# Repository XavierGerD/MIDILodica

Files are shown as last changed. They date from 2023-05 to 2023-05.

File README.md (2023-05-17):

# MIDILodica

## What is the MIDILodica?

<p align="center">
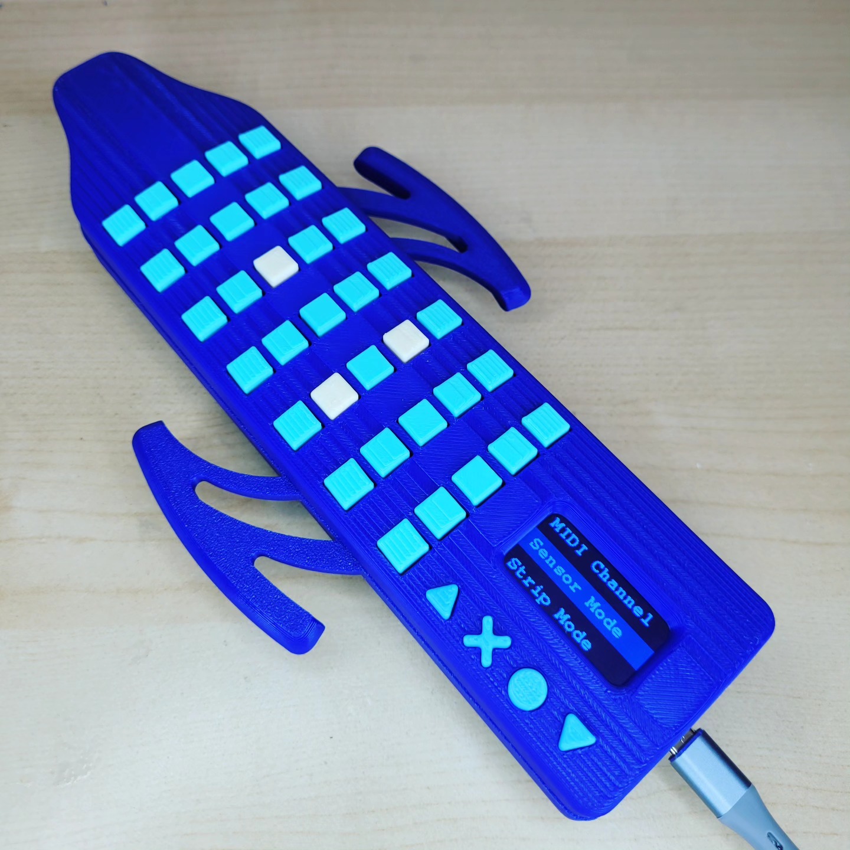
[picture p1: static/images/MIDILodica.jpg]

</p>

The MIDILodica is a breath-controlled, 3D printed, open-source MIDI device that features a pressure sensor, 35 reassignable note buttons, a softpot strip potentiometer, full menu navigation with a 320x172 screen, and underside button for additional MIDI and octave manipulation. This repository contains all the files needed to 3D print and manufacture the MIDILodica.

To accomplish this project, you will need:

- Basic knowledge of the Arduino IDE.
- Basic knowledge of and equipment for soldering.
- Access to a 3D printer.
- All the electronic parts listed below.

</br>

## Parts list

To build the MIDILodica, you will need the following:

- **40 x TL1105SPF160Q Tactile Switch** (can be substituted with TL1240NQ1JBLK if you don't have access to a 3D printer)
- **1x Adafruit 320x172 TFT Display - ST7789 (part no. 5393)** (with headers)
- **1x Arduino Micro** (with headers)
- **40x 1N4148 Through-hole diodes**
- **1x 10k through-hole resistor**
- **1x ABPDANT005PGAA5 Honeywell pressure sensor**
- **1x SEN-08680 50mm Softpot**
- **1x 66226-003LF 3pos clincher** (to replace the Softpot headers)
- **3x Male to Female jumper cables OR 1x 3pos Male to Female jumper cable**
- **1x 3pos right angle header** (to hold the sensor breakout board)
- **6x M2x20 screws** (for the housing)
- **4x M2x8 screws** (for the strip pot plate)

You will also need to obtain TWO printed circuit boards (PCB) with a PCB manufacturing service. The first one is the main board, which has all the buttons and breakout boards. The second PCB holds the sensor, and is attached at a 90 degree angle using the 3pos right angle header. The required files are in a .zip in the `/manufacturing/gerber` folder. If you wish to modify these boards, the `.sch` and `.brd` files are available in the `/manufacturing` folder.

</br>

## License

The project is under the GNU General Public License v3.0.

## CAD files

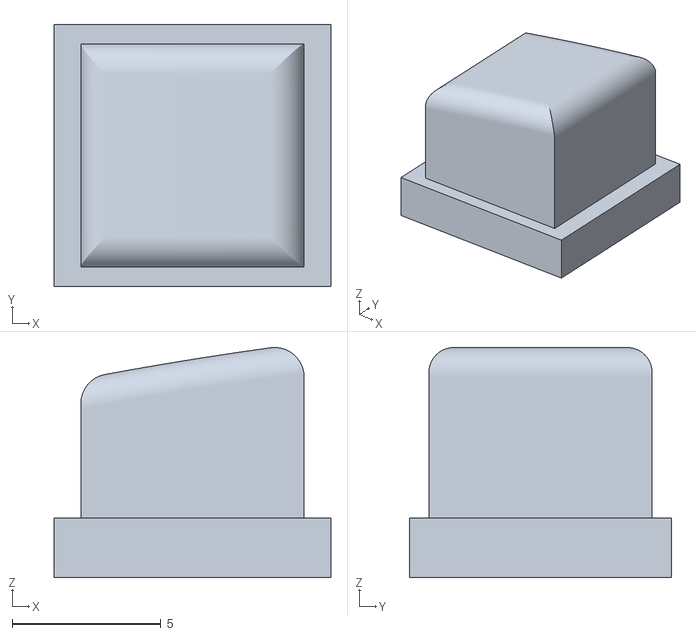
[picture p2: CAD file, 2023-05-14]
stl/Outer Button.stl
9.30 x 8.80 x 7.72

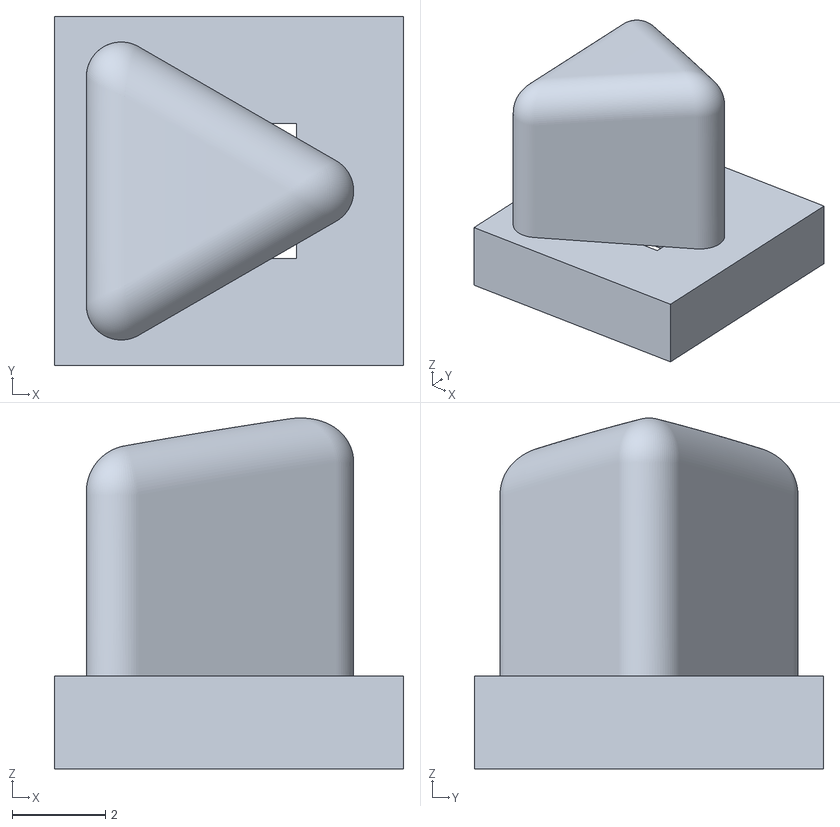
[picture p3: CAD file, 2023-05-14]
stl/Up Button.stl
7.50 x 7.50 x 7.54

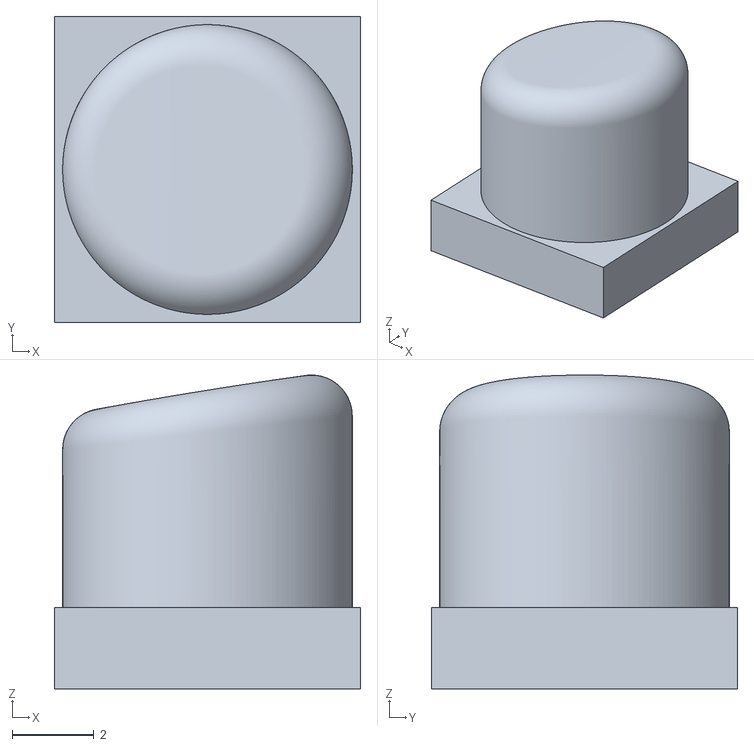
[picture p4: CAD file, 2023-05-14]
stl/Confirm Button.stl
7.50 x 7.50 x 7.69

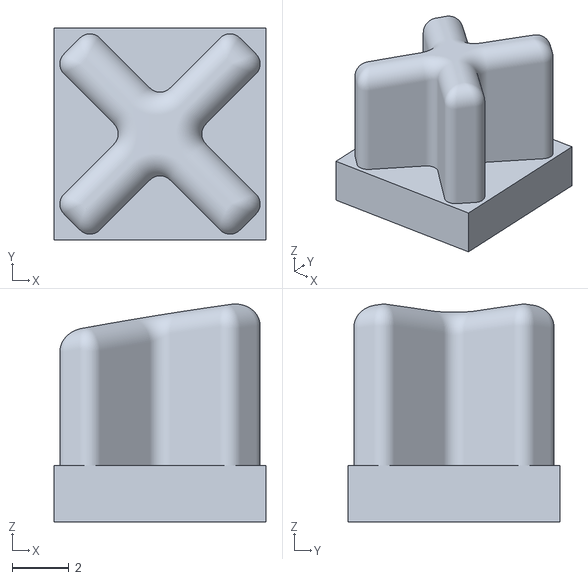
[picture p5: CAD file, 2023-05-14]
stl/Cancel Button.stl
7.50 x 7.50 x 7.71

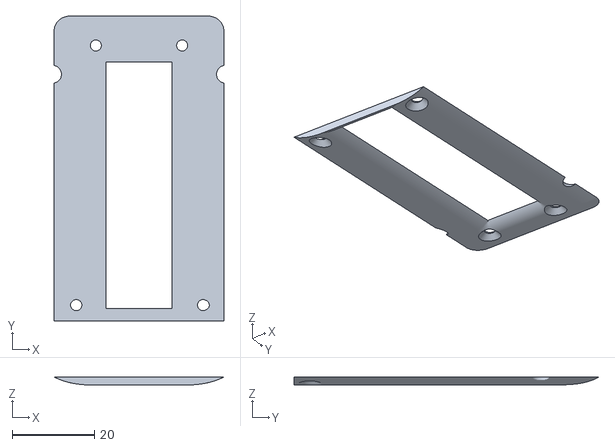
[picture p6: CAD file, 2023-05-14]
stl/Strip Cover.stl
41.3 x 74.2 x 2.00

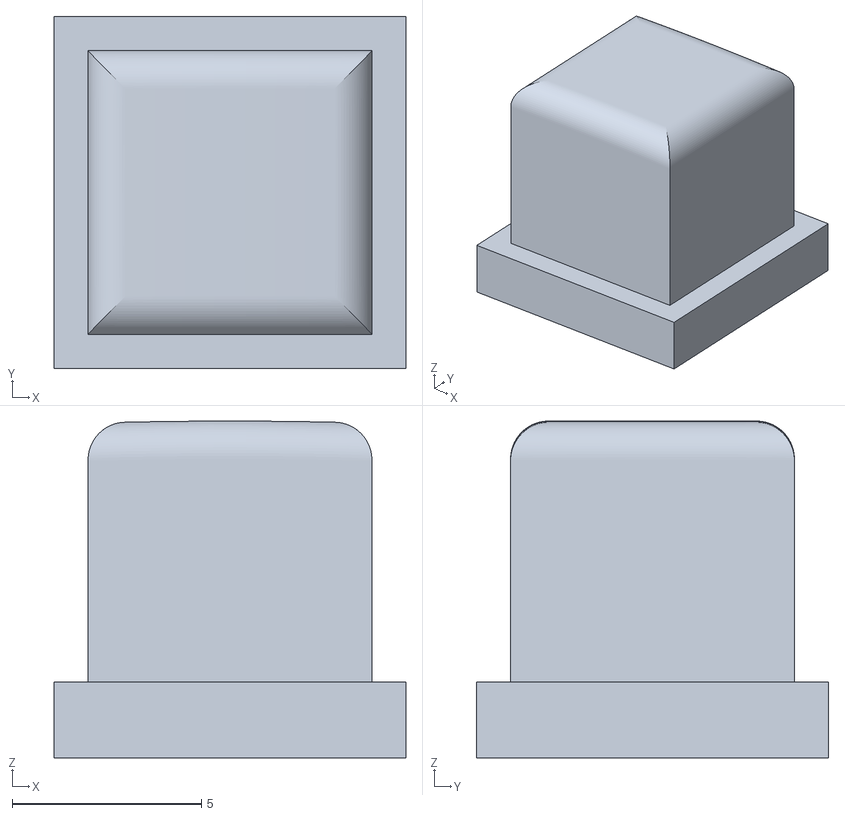
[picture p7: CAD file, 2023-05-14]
stl/Middle Button.stl
9.30 x 9.30 x 8.90

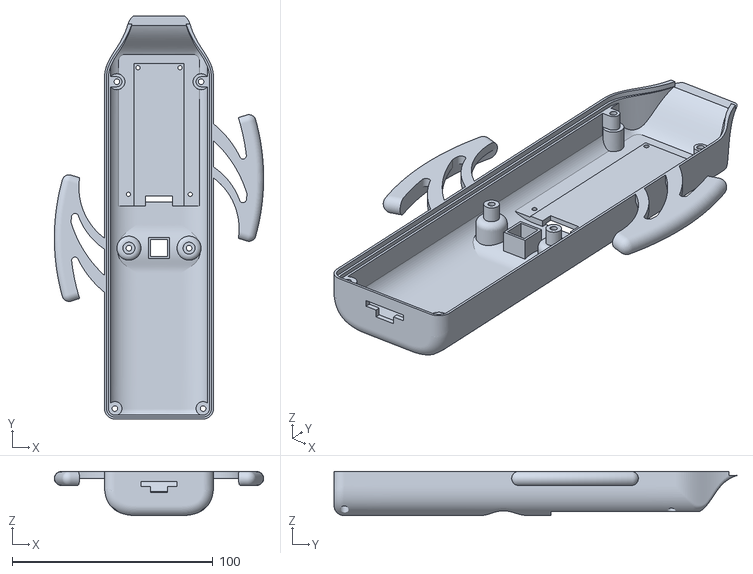
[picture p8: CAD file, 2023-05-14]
stl/Bottom_with_wings.stl
104.4 x 201.0 x 22.0

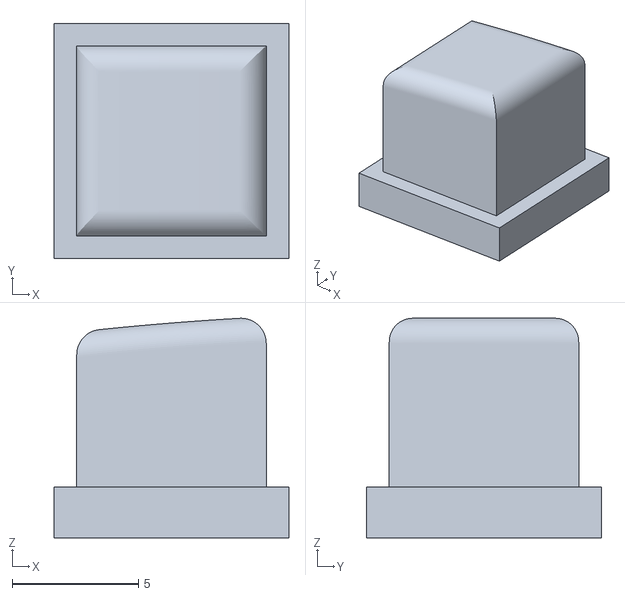
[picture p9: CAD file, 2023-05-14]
stl/Inner Button.stl
9.30 x 9.30 x 8.69

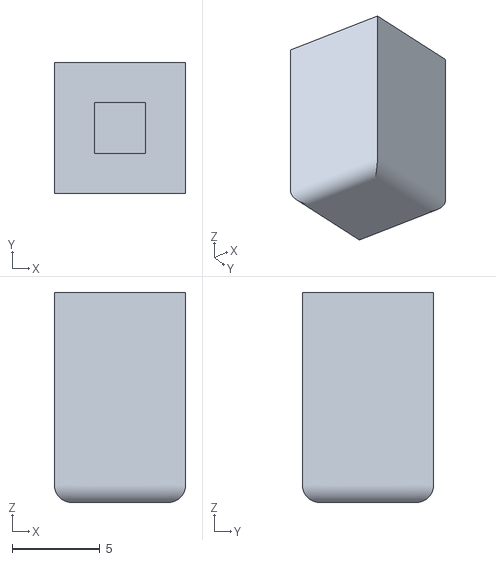
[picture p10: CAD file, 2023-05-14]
stl/Underbutton.stl
7.50 x 7.50 x 12.0

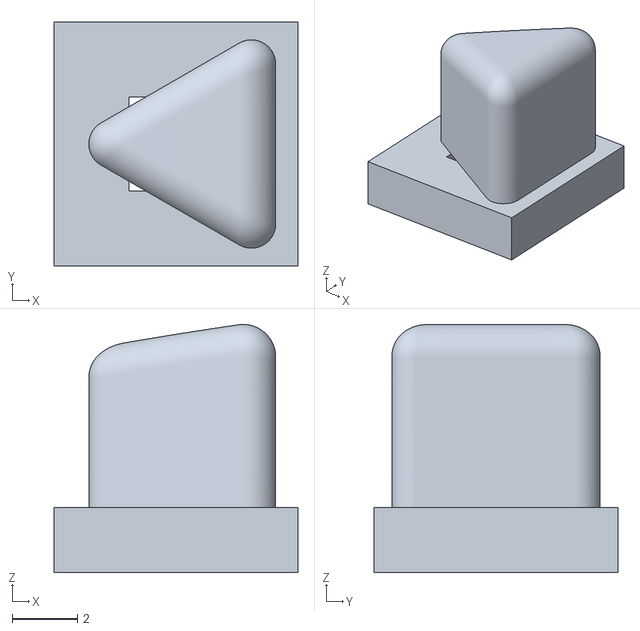
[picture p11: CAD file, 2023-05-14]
stl/Down Button.stl
7.50 x 7.50 x 7.63

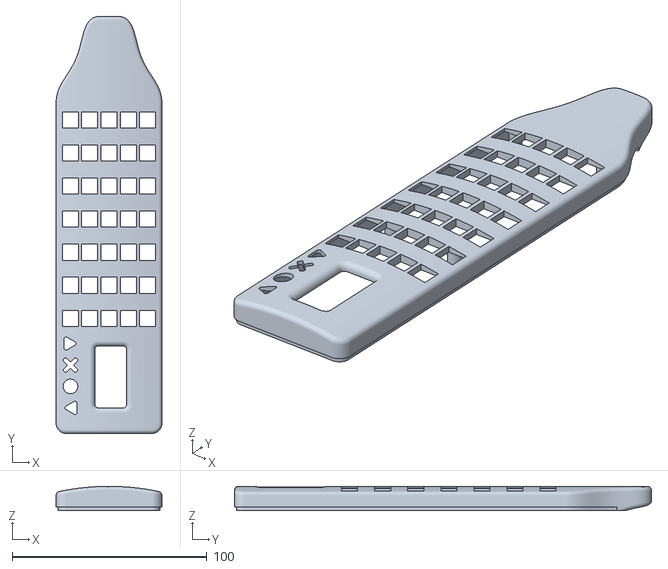
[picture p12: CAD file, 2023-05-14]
stl/Top.stl
54.4 x 214.4 x 12.5

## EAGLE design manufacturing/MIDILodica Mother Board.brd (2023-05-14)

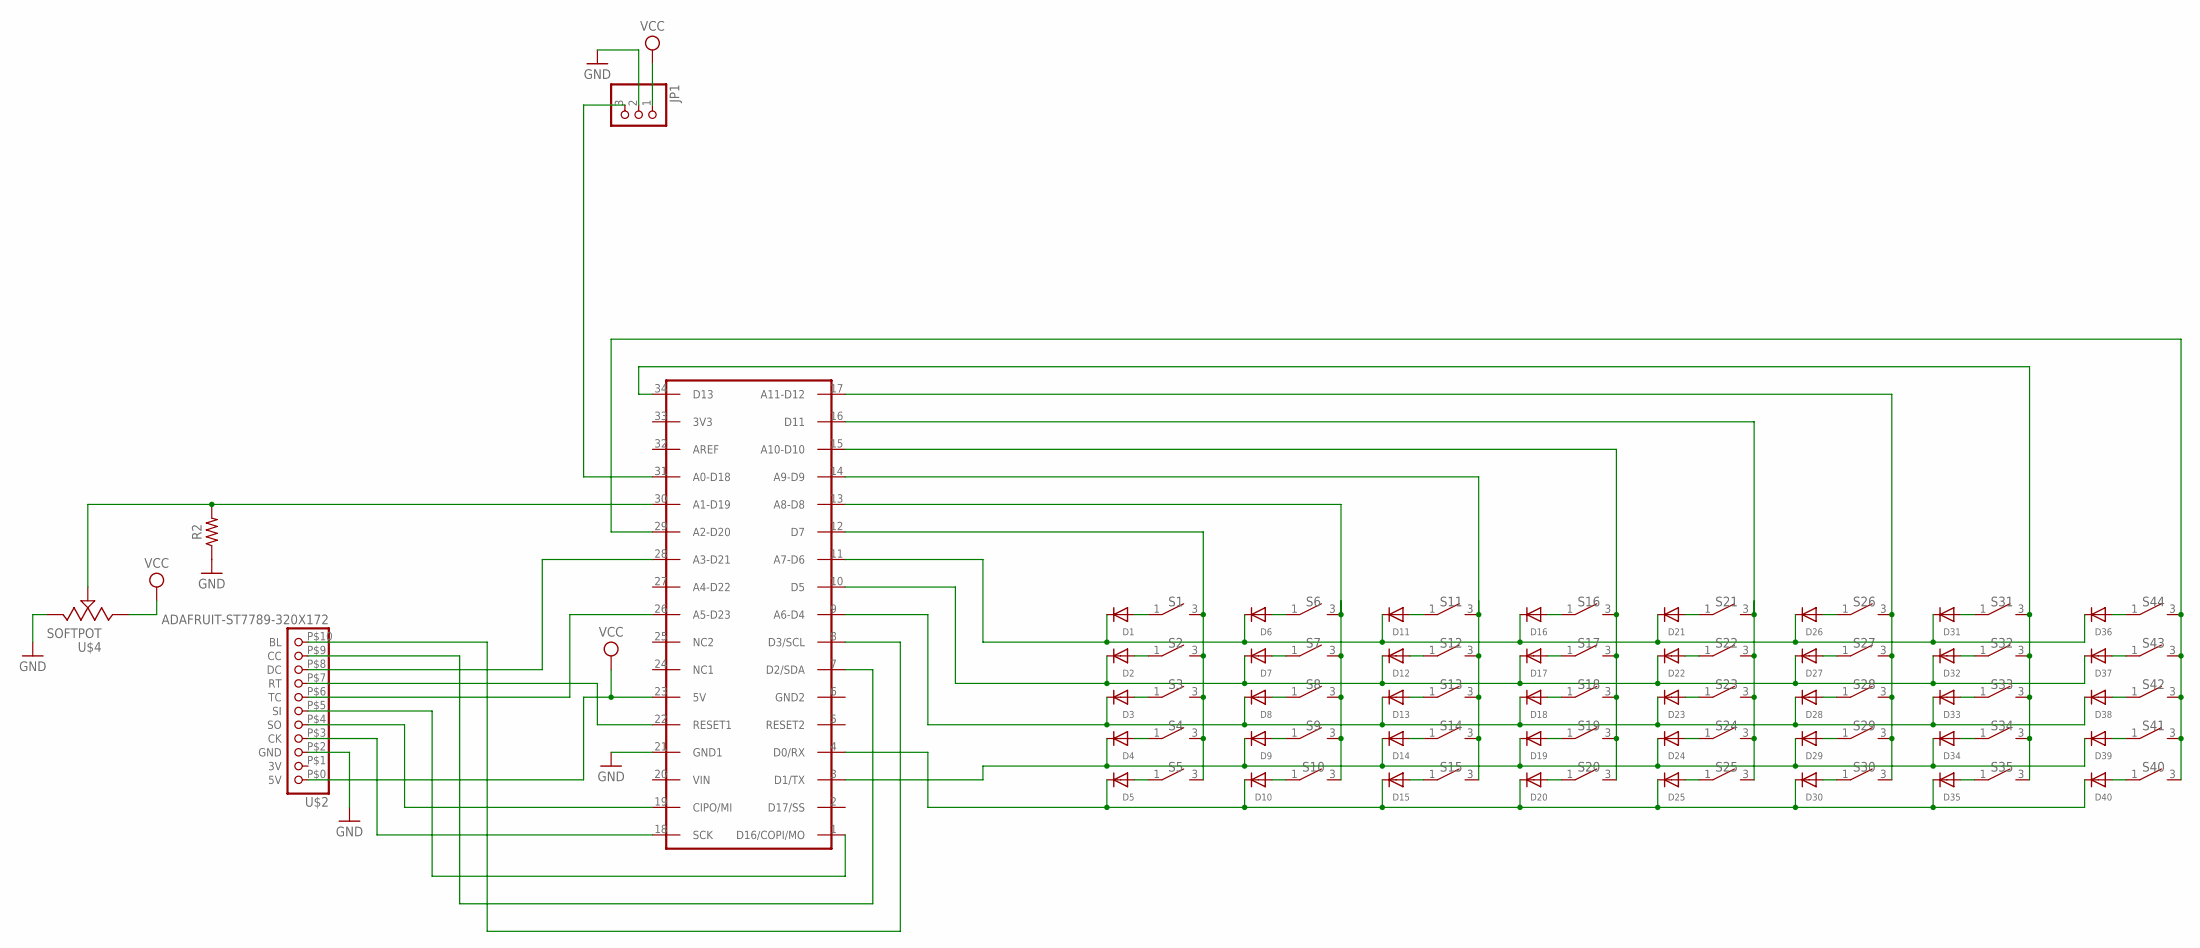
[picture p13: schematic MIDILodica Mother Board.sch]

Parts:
D1, D2, D3, D4, D5, D6, D7, D8, D9, D10, D11, D12, D13, D14, D15, D16, D17, D18, D19, D20, D21, D22, D23, D24, D25, D26, D27, D28, D29, D30, D31, D32, D33, D34, D35, D36, D37, D38, D39, D40: DIODEDO-1N4148; DO-1N4148
JP1: PINHD-1X3; 1X03
R2: R-US_AXIAL-7.2MM-PITCH; RESAD724W46L381D178B
S1, S2, S3, S4, S5, S6, S7, S8, S9, S10, S11, S12, S13, S14, S15, S16, S17, S18, S19, S20, S21, S22, S23, S24, S25, S26, S27, S28, S29, S30, S31, S32, S33, S34, S35, S40, S41, S42, S43, S44: TL1105SPF160Q
U$1: ARDUINO_MICRO; ARDUINO-MICRO
U$2: ADAFRUIT-ST7789-320X172
U$4: SOFTPOT; SOFTPOT-1

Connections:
5V+: JP1.1, U$1.23 (5V), U$2.P$0 (5V), U$4.1
GND: JP1.2, R2.1, U$1.21 (GND1), U$2.P$2 (GND), U$4.3
unnamed: R2.2, U$1.30 (A1-D19), U$4.2
unnamed: JP1.3, U$1.31 (A0-D18)
unnamed: D25.A, S25.1
unnamed: D24.A, S24.1
unnamed: D23.A, S23.1
unnamed: U$1.26 (A5-D23), U$2.P$6 (TC)
unnamed: D4.C, D9.C, D14.C, D19.C, D24.C, D29.C, D34.C, D39.C, U$1.3 (D1/TX)
unnamed: D22.A, S22.1
unnamed: D39.A, S41.1
unnamed: D38.A, S42.1
unnamed: D37.A, S43.1
unnamed: D1.A, S1.1
unnamed: D2.A, S2.1
unnamed: D3.A, S3.1
unnamed: D4.A, S4.1
unnamed: D5.A, S5.1
unnamed: D10.A, S10.1
unnamed: D9.A, S9.1
unnamed: D8.A, S8.1
unnamed: D7.A, S7.1
unnamed: D6.A, S6.1
unnamed: D36.A, S44.1
unnamed: D21.A, S21.1
unnamed: S40.3 (2), S41.3 (2), S42.3 (2), S43.3 (2), S44.3 (2), U$1.29 (A2-D20)
unnamed: D30.A, S30.1
unnamed: D29.A, S29.1
unnamed: D28.A, S28.1
unnamed: U$1.22 (RESET1), U$2.P$7 (RT)
unnamed: D27.A, S27.1
unnamed: D26.A, S26.1
unnamed: U$1.28 (A3-D21), U$2.P$8 (DC)
unnamed: D35.A, S35.1
unnamed: D34.A, S34.1
unnamed: D11.A, S11.1
unnamed: D12.A, S12.1
unnamed: D13.A, S13.1
unnamed: D14.A, S14.1
unnamed: D15.A, S15.1
unnamed: D20.A, S20.1
unnamed: D19.A, S19.1
unnamed: D18.A, S18.1
unnamed: D17.A, S17.1
unnamed: D16.A, S16.1
unnamed: D33.A, S33.1
unnamed: D32.A, S32.1
unnamed: D31.A, S31.1
unnamed: U$1.18 (SCK), U$2.P$3 (CK)
unnamed: U$1.19 (CIPO/MI), U$2.P$4 (SO)
unnamed: U$1.7 (D2/SDA), U$2.P$9 (CC)
unnamed: U$1.8 (D3/SCL), U$2.P$10 (BL)
unnamed: U$1.1 (D16/COPI/MO), U$2.P$5 (SI)
unnamed: D1.C, D6.C, D11.C, D16.C, D21.C, D26.C, D31.C, D36.C, U$1.11 (A7-D6)
unnamed: D2.C, D7.C, D12.C, D17.C, D22.C, D27.C, D32.C, D37.C, U$1.10 (D5)
unnamed: D3.C, D8.C, D13.C, D18.C, D23.C, D28.C, D33.C, D38.C, U$1.9 (A6-D4)
unnamed: D5.C, D10.C, D15.C, D20.C, D25.C, D30.C, D35.C, D40.C, U$1.4 (D0/RX)
unnamed: D40.A, S40.1
unnamed: S1.3 (2), S2.3 (2), S3.3 (2), S4.3 (2), S5.3 (2), U$1.12 (D7)
unnamed: S6.3 (2), S7.3 (2), S8.3 (2), S9.3 (2), S10.3 (2), U$1.13 (A8-D8)
unnamed: S11.3 (2), S12.3 (2), S13.3 (2), S14.3 (2), S15.3 (2), U$1.14 (A9-D9)
unnamed: S16.3 (2), S17.3 (2), S18.3 (2), S19.3 (2), S20.3 (2), U$1.15 (A10-D10)
unnamed: S21.3 (2), S22.3 (2), S23.3 (2), S24.3 (2), S25.3 (2), U$1.16 (D11)
unnamed: S26.3 (2), S27.3 (2), S28.3 (2), S29.3 (2), S30.3 (2), U$1.17 (A11-D12)
unnamed: S31.3 (2), S32.3 (2), S33.3 (2), S34.3 (2), S35.3 (2), U$1.34 (D13)

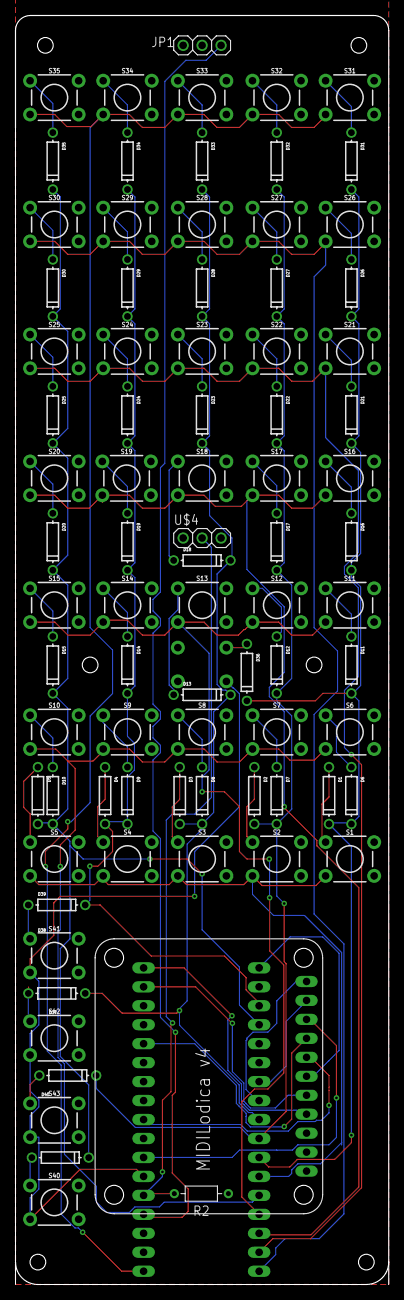
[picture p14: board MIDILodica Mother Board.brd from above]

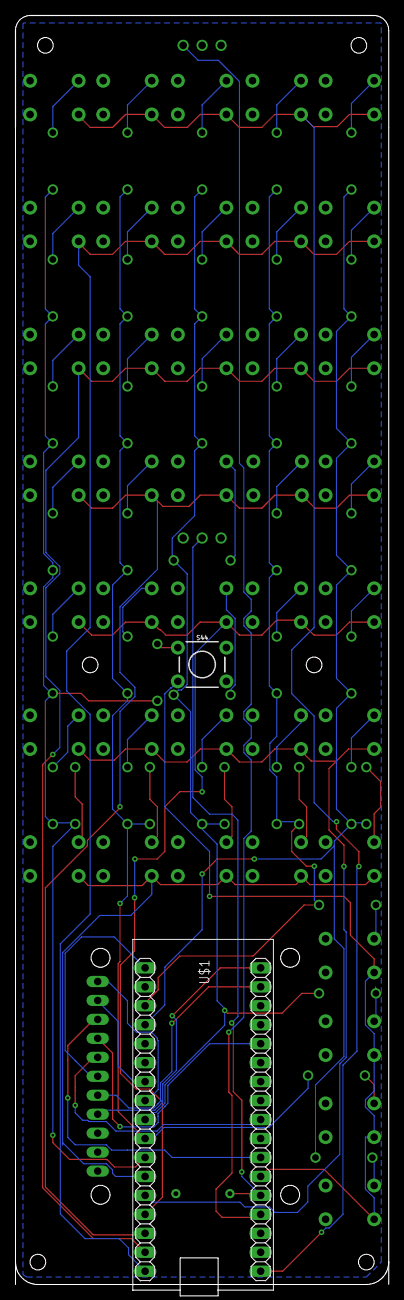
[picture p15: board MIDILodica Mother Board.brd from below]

Board: 2 copper layers, 50.0 x 170.0 mm, 85 parts (2 on the bottom side), 65 nets.

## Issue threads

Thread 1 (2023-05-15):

Files?

ogrotten, 2023-05-15:
>  The required files are in a .zip in the `/gerber` folder.

Except there is no `/gerber` folder?

XavierGerD, 2023-05-15:
Sorry, it's in the manufacturing folder. I'll create a PR shortly.

XavierGerD, 2023-05-16:
Closing now since I updated the PR.

Closed 2023-05-16.

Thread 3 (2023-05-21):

Lower cost sensors

riban-bw, 2023-05-21:
What led you to use the expensive Honeywell pressure sensor? Did you try lower cost options like https://www.digikey.co.uk/en/products/detail/omron-electronics-inc-emc-div/2SMPP-02/2504247?

I also wonder if there is merit in trying a DIY slide pressure sensor using two adjacent triangular strips of velostat? (I think I saw it done like that.)

XavierGerD, 2023-06-03:
Hey, sorry for the late reply.

I hadn't seen those low-cost sensors when I made the prototype, but they look very appealing indeed! I will definitely acquire a couple of them and try them out. Thanks!

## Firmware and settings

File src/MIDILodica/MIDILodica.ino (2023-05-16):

#include <frequencyToNote.h>
#include <MIDIUSB.h>
#include <MIDIUSB_Defs.h>
#include <pitchToFrequency.h>
#include <pitchToNote.h>
#include "NoteButton.h"
#include "Menu.h"
#include "Scales.h"
#include <Adafruit_GFX.h>
#include <Adafruit_ST7789.h>
#include <Fonts/FreeMonoBold9pt7b.h>

#define numberOfButtons 35

#define sensorPin 18
#define stripPin 19
#define menuDown 21
#define menuSelect 22
#define menuUp 20

#define TFT_CS        23
#define TFT_RST       -1
#define TFT_DC        21

#define SCREEN_WIDTH 320
#define SCREEN_HEIGHT 172

Adafruit_ST7789 tft = Adafruit_ST7789(TFT_CS, TFT_DC, TFT_RST);

#define C7 7
#define C6 8
#define C5 9
#define C4 10
#define C3 11
#define C2 12
#define C1 13
// Used for menu controls and underbutton
#define C8 20

#define R5 0
#define R4 1
#define R3 4
#define R2 5
#define R1 6

#define underButton 20

#define rowsLength 5
#define columnsLength 7

#define backgroundColor 0x5151
#define textColor 0xAE7F
#define textShadowColor 0x2318
#define selectedColor 0x3C7A

byte rows[rowsLength] = { R1, R2, R3, R4, R5 };
byte columns[columnsLength] = { C1, C2, C3, C4, C5, C6, C7 };

byte startingNote = 60;

NoteButton *noteButtons[rowsLength][columnsLength];

// MIDIFlute config

// Sensor modes:
const byte SENSOR_VELOCITY = 0;
const byte SENSOR_MOD_WHEEL = 1;
const byte SENSOR_PITCH_BEND = 2;
const byte SENSOR_OCTAVE_SHIFT = 3;
const byte SENSOR_OFF = 4;
const byte SENSOR_CUSTOM_CC = 5;

byte sensorMode = SENSOR_MOD_WHEEL;

// Under button modes:
const byte UNDER_BUTTON_8VA_UP = 0;
const byte UNDER_BUTTON_8VA_DOWN = 1;
const byte UNDER_BUTTON_SUSTAIN = 2;

byte underButtonMode = 0;

// Strip pot modes:
const byte STRIP_VELOCITY = 0;
const byte STRIP_MOD_WHEEL = 1;
const byte STRIP_PITCH_BEND = 2;
const byte STRIP_OFF = 3;
const byte STRIP_CUSTOM_CC = 4;

byte stripSensorMode = 2;

byte currentScale = 0;
byte currentStartingNote = 0;
byte currentStartingOctave = 4;
byte currentSensitivity = 1;

int currentChannel = 0;
int sensorMIDICC = 0;
int stripMIDICC = 0;

byte settingsLength = 7;

byte sensorSensitivities[4] = {200, 175, 150, 125};
byte minimumSensitivity = 100;

byte nextVal;

byte nextStripVal;

byte increment = 4;
uint16_t colors[] = { textColor, 0x545d, textShadowColor };

void showSplashScreen() {
  for (int i = 2; i >= 0; i--) {
    tft.setTextColor(colors[i]);
    tft.setCursor(72 - (increment * i), 70 + (increment * i));
    tft.print("MIDI");
    tft.setCursor(25 - (increment * i), 130  + (increment * i));
    tft.print("LODICA");
  }

  delay(3000);
}

void launchScreen() {
  tft.init(SCREEN_HEIGHT, SCREEN_WIDTH);
  tft.setRotation(1);
  tft.fillScreen(backgroundColor);

  tft.setTextSize(4);
  tft.setFont(&FreeMonoBold9pt7b);

  showSplashScreen();

  tft.setTextColor(textColor);
  tft.setTextSize(2);
  drawMenu();
}

void setup() {
  pinMode(stripPin, INPUT);
  pinMode(sensorPin, INPUT);
  digitalWrite(17, HIGH);
  for (byte i = 0; i < rowsLength; i++) {
    pinMode(rows[i], INPUT);
  }

  for (byte j = 0; j < columnsLength; j++) {
    pinMode(columns[j], INPUT_PULLUP);
    digitalWrite(columns[j], HIGH);
  }

  pinMode(C8, INPUT_PULLUP);
  digitalWrite(C8, HIGH);

  Serial.begin(9600);

  launchScreen();
  initializeButtons(currentStartingNote, currentStartingOctave, scales[currentScale], scaleLengths[currentScale]);
}

void loop() {
  playMIDINotes();
  int sensorPinVal = analogRead(sensorPin);
  int constrainedSensorVal = constrain(analogRead(sensorPin), minimumSensitivity, sensorSensitivities[currentSensitivity]);

  // Avoid unwanted noise when idle.
  if (constrainedSensorVal <= 105) {
    constrainedSensorVal = 100;
  }

  byte sensorValue = map(constrainedSensorVal, minimumSensitivity, sensorSensitivities[currentSensitivity], 0, 127);

  if (sensorValue != nextVal) {
    handleSensorModes(sensorValue);
    nextVal = sensorValue;
  }

  int stripPinVal = analogRead(stripPin);
  int stripVal = map(stripPinVal, 0, 1000, 0, 127);
  stripVal = constrain(stripVal, 0, 127);
  
  if (stripVal != nextStripVal) {
    handleStripVal(stripVal);
    nextStripVal = stripVal;
  }
}

void handleSensorModes(byte sensorVal) {
  // YES I KNOW but the switch here isn't working properly
  // for reasons I don't understand. So this will have to do.
  if (sensorMode == SENSOR_VELOCITY) {
    velocity = sensorVal;
  } else if (sensorMode == SENSOR_MOD_WHEEL) {
    midiEventPacket_t ccModWheel = {0x0B, 0xB0 | currentChannel, 1, sensorVal};
    MidiUSB.sendMIDI(ccModWheel);
  } else if (sensorMode == SENSOR_PITCH_BEND) {
    midiEventPacket_t sensorPitchBendChange = {0x0B, 0xE0 | currentChannel, 1, sensorVal};
    MidiUSB.sendMIDI(sensorPitchBendChange);
  } else if (sensorMode == SENSOR_OCTAVE_SHIFT) {
    handleSensorOctaveShift(sensorVal);
  } else if (sensorMode == SENSOR_OFF) {
    return;
  } else if (sensorMode == SENSOR_CUSTOM_CC) {
    midiEventPacket_t ccMessage = {0x0B, 0xB0 | currentChannel, sensorMIDICC, sensorVal};
    MidiUSB.sendMIDI(ccMessage);
  }

  MidiUSB.flush();
}

void handleStripVal(int stripVal) {
  // YES I KNOW but the switch here isn't working properly
  // for reasons I don't understand. So this will have to do.
  if (stripSensorMode == STRIP_VELOCITY) {
    velocity = stripVal;
  } else if (stripSensorMode == STRIP_MOD_WHEEL) {
    midiEventPacket_t ccChange = {0x0B, 0xB0 | currentChannel, 1, stripVal};
    MidiUSB.sendMIDI(ccChange);
  } else if (stripSensorMode == STRIP_PITCH_BEND) {
    midiEventPacket_t stripPitchBendChange = {0x0B, 0xE0 | currentChannel, 1, stripVal};
    Serial.println(stripVal);
    MidiUSB.sendMIDI(stripPitchBendChange);
  } else if (stripSensorMode == STRIP_OFF) {
    return;
  } else if (stripSensorMode == STRIP_CUSTOM_CC) {
    midiEventPacket_t ccMessage = {0x0B, 0xB0 | currentChannel, stripMIDICC, stripVal};
    MidiUSB.sendMIDI(ccMessage);
  }

  MidiUSB.flush();

}

byte lastOctave = currentStartingOctave;

void handleSensorOctaveShift(byte sensorVal) {
  byte sensorOctaveShift = map(sensorVal, 0, 127, 0, 3);
  byte newOctave = currentStartingOctave + sensorOctaveShift;

  if (lastOctave != newOctave) {
    assignNotesToButtons(currentStartingNote, newOctave, scales[currentScale], scaleLengths[currentScale]);
    lastOctave = newOctave;
  }

}

byte offset = 2;
void drawTextWithShadow(char* text, byte x, byte y) {
  tft.setTextColor(0x545d);
  tft.setCursor(x - offset, y + offset);
  tft.print(text);

  tft.setTextColor(textColor);
  tft.setCursor(x, y);
  tft.print(text);
}


void updateNumberSelectMenuScreen(char* menuName, byte menuNameLength, char value[4], byte selectedIndex, bool isMaximumThreeDigits) {
  tft.fillScreen(backgroundColor);
  tft.setTextSize(2);

  byte menuNameX = (tft.width() / 2) - (22 * menuNameLength / 2);
  drawTextWithShadow(menuName, menuNameX, 50);

  tft.setTextSize(4);

  byte indexOffset = 1;
  if (isMaximumThreeDigits) {
    indexOffset = 2;
  }

  byte textX;
  if (isMaximumThreeDigits) {
    textX = (tft.width() / 2) - (44 * 3 / 2);
    drawTextWithShadow(value, textX, 120);
  } else {
    textX = (tft.width() / 2) - (44 * 2 / 2);
    char shortenedValue[] = {value[1], value[2]};
    drawTextWithShadow(shortenedValue, textX, 120);
  }

  byte underscorePositionOffset = (44 * (indexOffset - selectedIndex));
  drawTextWithShadow("_", textX + underscorePositionOffset, 120);
}

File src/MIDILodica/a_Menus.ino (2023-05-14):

#define menusLength 10
#define settingsLength 10
#define sensorLength 6
#define stripLength 5
#define scaleLength 14
#define startingNoteLength 12
#define startingOctaveLength 9
#define sensitivityLength 4
#define underButtonLength 3
#define patchLength 10

byte currentMenu = 0;
int currentNumberSelectMenu = -1;
int currentMenuItem = 0;

int getSettingsMenuSelectedValue() {
  return -1;
}

Menu settingsMenuItems[settingsLength] = {
  Menu("Sensor Mode", 1, navigateToSubmenu, getSettingsMenuSelectedValue),
  Menu("Strip Mode", 2, navigateToSubmenu, getSettingsMenuSelectedValue),
  Menu("Scale", 3, navigateToSubmenu, getSettingsMenuSelectedValue),
  Menu("Tonic", 4, navigateToSubmenu, getSettingsMenuSelectedValue),
  Menu("Octave", 5, navigateToSubmenu, getSettingsMenuSelectedValue),
  Menu("Sensitivity", 6, navigateToSubmenu, getSettingsMenuSelectedValue),
  Menu("Under button", 7, navigateToSubmenu, getSettingsMenuSelectedValue),
  Menu("Save", 8, navigateToSubmenu, getSettingsMenuSelectedValue),
  Menu("Load", 9, navigateToSubmenu, getSettingsMenuSelectedValue),

  // submenu is 1 here because it belongs to the allNumberSelectMenus list and not the regular allMenus list.
  Menu("MIDI Channel", 0, navigateToNumberSelectSubmenu, getSettingsMenuSelectedValue),

};

int getSelectedSensorMode() {
  return sensorMode;
}

void changeSetting(byte setting) {
  sensorMode = setting;
  navigateToSubmenu(0);
}

Menu sensorModeMenuItems[sensorLength] = {
  Menu("Velocity", SENSOR_VELOCITY, changeSetting, getSelectedSensorMode),
  Menu("Mod Wheel", SENSOR_MOD_WHEEL, changeSetting, getSelectedSensorMode),
  Menu("Pitch Bend", SENSOR_PITCH_BEND, changeSetting, getSelectedSensorMode),
  Menu("Octave Shift", SENSOR_OCTAVE_SHIFT, changeSetting, getSelectedSensorMode),
  Menu("Off", SENSOR_OFF, changeSetting, getSelectedSensorMode),
  // submenu is 1 here because it belongs to the allNumberSelectMenus list and not the regular allMenus list.
  Menu("Custom CC", 1, navigateToNumberSelectSubmenu, getSelectedSensorMode),
};

int getSelectedStripMode() {
  return stripSensorMode;
}

void changeStripSetting(byte setting) {
  stripSensorMode = setting;

  // Restore velocity.
  if (setting != 0) {
    velocity = 127;
  }
  navigateToSubmenu(0);
}

Menu stripModeMenuItems[stripLength] = {
  Menu("Velocity", STRIP_VELOCITY, changeStripSetting, getSelectedStripMode),
  Menu("Mod Wheel", STRIP_MOD_WHEEL, changeStripSetting, getSelectedStripMode),
  Menu("Pitch Bend", STRIP_PITCH_BEND, changeStripSetting, getSelectedStripMode),
  Menu("Off", STRIP_OFF, changeStripSetting, getSelectedStripMode),
  // submenu is 1 here because it belongs to the allNumberSelectMenus list and not the regular allMenus list.
  Menu("Custom CC", 2, navigateToNumberSelectSubmenu, getSelectedStripMode),
};

int getSelectedScale() {
  return currentScale;
}

void changeScale(byte note) {
  currentScale = currentMenuItem;
  endMenuInteraction();
}

Menu scaleMenuItems[scaleLength] = {
  Menu("Chromatic", 0, changeScale, getSelectedScale),
  Menu("Ionian", 1, changeScale, getSelectedScale),
  Menu("Dorian", 2, changeScale, getSelectedScale),
  Menu("Phryigian", 3, changeScale, getSelectedScale),
  Menu("Lydian", 4, changeScale, getSelectedScale),
  Menu("Mixolydian", 5, changeScale, getSelectedScale),
  Menu("Aeolian", 6, changeScale, getSelectedScale),
  Menu("Locrian", 7, changeScale, getSelectedScale),
  Menu("Mel. Minor", 8, changeScale, getSelectedScale),
  Menu("Penta. Maj.", 9, changeScale, getSelectedScale),
  Menu("Penta. Min.", 10, changeScale, getSelectedScale),
  Menu("Whole Tone", 11, changeScale, getSelectedScale),
  Menu("Octa. 2, 1", 12, changeScale, getSelectedScale),
  Menu("Octa. 1, 2", 13, changeScale, getSelectedScale),
};

int getStartingNote() {
  return currentStartingNote;
}

void changeStartingNote(byte note) {
  currentStartingNote = note;
  endMenuInteraction();
}

Menu startingNoteMenuItems[startingNoteLength] = {
  Menu("C", 0, changeStartingNote, getStartingNote),
  Menu("Db", 1, changeStartingNote, getStartingNote),
  Menu("D", 2, changeStartingNote, getStartingNote),
  Menu("Eb", 3, changeStartingNote, getStartingNote),
  Menu("E", 4, changeStartingNote, getStartingNote),
  Menu("F", 5, changeStartingNote, getStartingNote),
  Menu("Gb", 6, changeStartingNote, getStartingNote),
  Menu("G", 7, changeStartingNote, getStartingNote),
  Menu("Ab", 8, changeStartingNote, getStartingNote),
  Menu("A", 9, changeStartingNote, getStartingNote),
  Menu("Bb", 10, changeStartingNote, getStartingNote),
  Menu("B", 11, changeStartingNote, getStartingNote),
};

int getStartingOctave() {
  return currentStartingOctave;
}

void changeStartingOctave(byte octave) {
  currentStartingOctave = octave;
  endMenuInteraction();
}

Menu startingOctaveMenuItems[startingOctaveLength] = {
  Menu("0", 0, changeStartingOctave, getStartingOctave),
  Menu("1", 1, changeStartingOctave, getStartingOctave),
  Menu("2", 2, changeStartingOctave, getStartingOctave),
  Menu("3", 3, changeStartingOctave, getStartingOctave),
  Menu("4", 4, changeStartingOctave, getStartingOctave),
  Menu("5", 5, changeStartingOctave, getStartingOctave),
  Menu("6", 6, changeStartingOctave, getStartingOctave),
  Menu("7", 7, changeStartingOctave, getStartingOctave),
  Menu("8", 8, changeStartingOctave, getStartingOctave),
};

int getSensitivity() {
  return currentSensitivity;
}

void changeSensitivity(byte setting) {
  currentSensitivity = setting;
  endMenuInteraction();
}

Menu sensitivityMenuItems[sensitivityLength] = {
  Menu("Low", 0, changeSensitivity, getSensitivity),
  Menu("Medium", 1, changeSensitivity, getSensitivity),
  Menu("High", 2, changeSensitivity, getSensitivity),
  Menu("Very High", 3, changeSensitivity, getSensitivity),
};

int getUnderButtonMode() {
  return underButtonMode;
}

void changeUnderButtonMode(byte newValue) {
  underButtonMode = newValue;
  endMenuInteraction();
}

Menu underButtonMenuItems[underButtonLength] = {
  Menu("Octave Up", UNDER_BUTTON_8VA_UP, changeUnderButtonMode, getUnderButtonMode),
  Menu("Octave Down", UNDER_BUTTON_8VA_DOWN, changeUnderButtonMode, getUnderButtonMode),
  Menu("Sustain", UNDER_BUTTON_SUSTAIN, changeUnderButtonMode, getUnderButtonMode),
};

int getPatch() {
  return -1;
}

void savePatch(byte startingLocation) {
  savePatchInternal(startingLocation);
  endMenuInteraction();
}

Menu savePatchMenuItems[patchLength] = {
  Menu("1", 0, savePatch, getPatch),
  Menu("2", 1, savePatch, getPatch),
  Menu("3", 2, savePatch, getPatch),
  Menu("4", 3, savePatch, getPatch),
  Menu("5", 4, savePatch, getPatch),
  Menu("6", 5, savePatch, getPatch),
  Menu("7", 6, savePatch, getPatch),
  Menu("8", 7, savePatch, getPatch),
  Menu("9", 8, savePatch, getPatch),
  Menu("10", 9, savePatch, getPatch),
};

void loadPatch(byte startingLocation) {
  loadProgramInternal(startingLocation);
  endMenuInteraction();
}
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
